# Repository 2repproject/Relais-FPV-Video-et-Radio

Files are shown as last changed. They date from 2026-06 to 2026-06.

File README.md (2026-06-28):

# Projet Relais FPV Video-Radio   

Ici vous trouve manuel d'utilisation et montage de composants puis le model **.stl**, le relais etait fabrique par **CPL Grib du 2REP**

### C'est qua au interieur projet:
* **Manuel de montage Relais fpv.pdf** - Instruction complete comment faire Montage/Parametrage/Composants
* **BOITE RELAIS.stl** - Le boite principal de relais
* **COUVERCLE RELAIS.stl** - Fermeture pour boite
* **vrx adapt 1 antenne.stl** - Adaptation/fixation du VRX au Boite relais (evite que VRX tombe)
* **vrx adapt 2 antenne.stl** - Adaptation/fixation du VRX au Boite relais (evite que VRX tombe)

### Comment telecharger📥:
*  **Telecharger direct au github⚡**:Appuie sur link pour telecharger tout le fichier [https://github.com/ivanopolon/Relais-FPV-Video-et-Radio/archive/refs/heads/main.zip]
*  **Deuxieme link Google Drive** : [https://drive.google.com/drive/folders/1ycLJLeQRHloeQPtYHDW72jciS7_rBkLo?usp=sharing]

### 💡Ce projet est ouvert a toutes les proposition d'amelioration! Si vous avez de idees pour optimiser les modeles, ajouter des fonctionnalites ou adapter les pieces pour autre configuration, votre aide est la bienvenue

**Comment participer🤝:**
  * **Proposer une idee:** Ouvrez un **"Issue"** pour discuter d'une modification ou d'une amelioration (dimensions, design, placement des composants).
  * **Partager vos modifications:** Si vous avez deja modifier un fichier STL de votre cote, n'hesitez pas a soumettre une **"Pull Request"**.
  * **Signaler un probleme:** Si vous remarquez un defaut d'impression ou un problemme d'ajustement sur le pieces, merci de le signaler dans l'onglet **Issues**

### Contacts 📬 
* **Email:** ivan.grib.2003@gmail.com
* **Telegram:** [👉 (https://t.me/Manuel_Gorbatiuc) 👈]
* **Disscusions:** Cree un theme dans onglets **"Disscusions"** pour communique de futurs et votre proposition soit problemme

### Conseils du impression 3D
* **Boite relais et couvercle:**
     *  **Material:** PETG soit PLA
     *  **Remplisage:** 20 a 30% gyroid
     *  **Supports:** Arbreuse (fait tourner model boite relais a 180 en **Y** pour que partie haut du relais etre en bas pendant impression)

 * **Vrx adapteur:**
     *  **Material:** TPU
     *  **Remplisage:** 15% Standart
     *  **Supports:** NON

### Principe de fonctionnement relais Video + Radio

Dans le contexte actuel de l'utilisation des drones (notamment les drones FPV kamikaze), la portée du signal se deminuer à une limite physique majeure : 
* **Zone montagneuses⛰️**
* **Zone forestieres et boisees dense🌳**
* **Environnement urbains**
* **Et tout le obstacle naturel**

Les signaux radio (comme l'ExpressLRS, Crossfire) et les Flux vidéo de differents frequances se coupent dès que le drone passe derrière l'obstacle (perte de la ligne de visée directe ou Line of Sight). 
Quelle que soit la puissance d'émission utilisée (même avec plusieurs Watts), la présence d'une masse physique bloque la reseau, entraînant une perte de contrôle et flux video immédiate.

### 💡 La Solution : Le Relais Embarqué sur Drone Porteur/(Observateur meme temps)
Pour surmonter tout le obstacle, ce projet propose une architecture de retransmission mobile. L'idée est de déployer un module de relais radio et vidéo fixé et allimenter sur un **Drone porteur** (drone mère). 

* **Rôle du drone porteur:** Placé en altitude stratégique, il sert de station relais volante et maintient une liaison parfaite entre l'opérateur au sol et le drone d'action. En meme temps faire observation
* **Fonctionnement Relais:** Le boîtier reçoit en temps réel les commandes de l'opérateur et le flux vidéo du drone d'attaque, puis les retransmet instantanément d'un point à un autre en contournant le relief.
* **Drone kamikaze:** Franchir le mouvement de terain et obstacle puis arrive a son point distribuie son perte signal

Grâce à cette liaison aérienne déportée, le drone peut accomplir sa mission avec succès derrière des obstacles topographiques complexes, garantissant la continuité du signal vidéo et radio jusqu'à l'objectif, peu importent les difficultés du terrain.

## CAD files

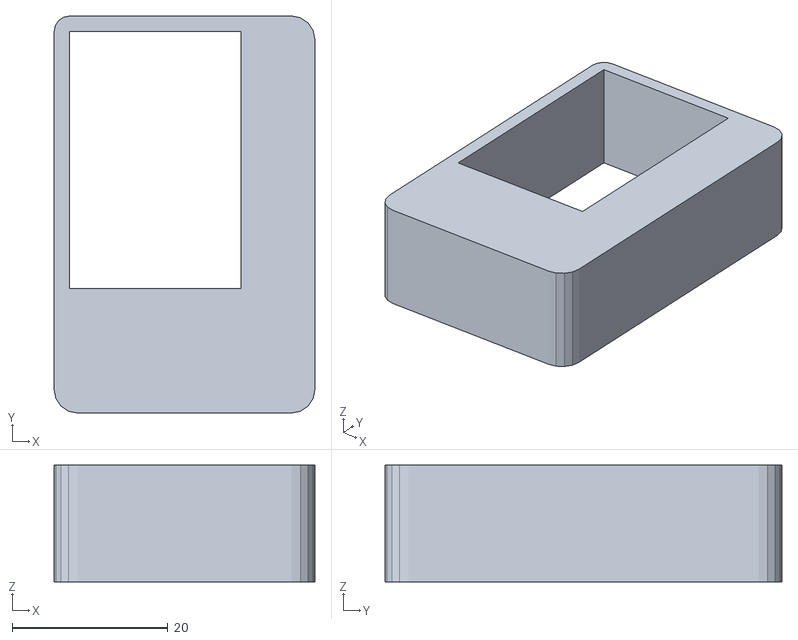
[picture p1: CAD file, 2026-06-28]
vrx adapt correct 1 antenne.stl
33.5 x 51.0 x 15.0

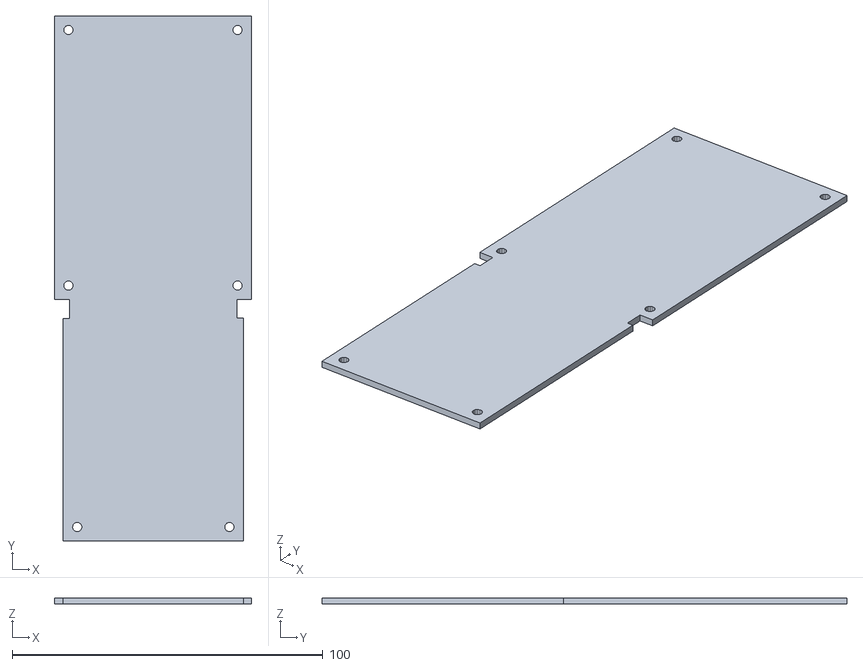
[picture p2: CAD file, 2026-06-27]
COUVERCLE RELAIS.stl
63.4 x 169.0 x 2.00

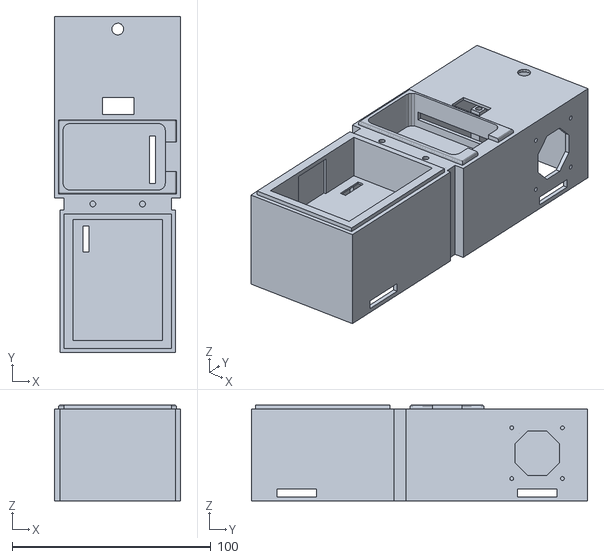
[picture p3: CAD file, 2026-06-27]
BOITE RELAIS.stl
63.4 x 169.0 x 48.2

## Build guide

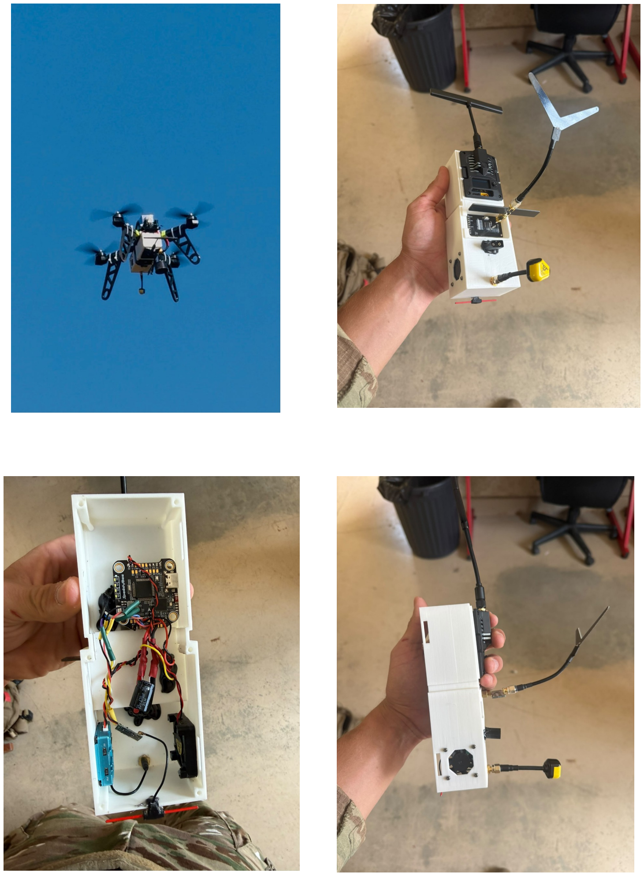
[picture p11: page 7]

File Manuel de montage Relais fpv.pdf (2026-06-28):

## RELAIS FPV Video + Controle

CPL GRIB 2REP

*Video 5.8ghz vers 1.2ghz
*ELRS 2.4ghz vers 915mhz
*Alimenter par drone porteur

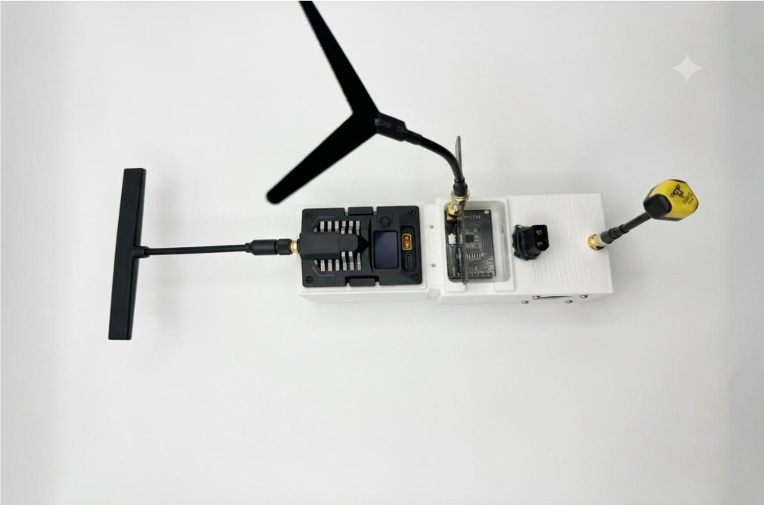
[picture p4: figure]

Dans le cadre de l'intégration drones FPV de type 'kamikaze' sur les guerres modernes, un probleme majeur a été identifié. Lors de la phase d'approche terminale vers l'objectif, la liaison radio directe subit de graves perturbations, allant jusqu'à la perte totale du signal.

Probleme majeur pour drone FPV c’etait:
*Zone montagneuses
*Zone forestieres et boisees dense *Environnement urbains

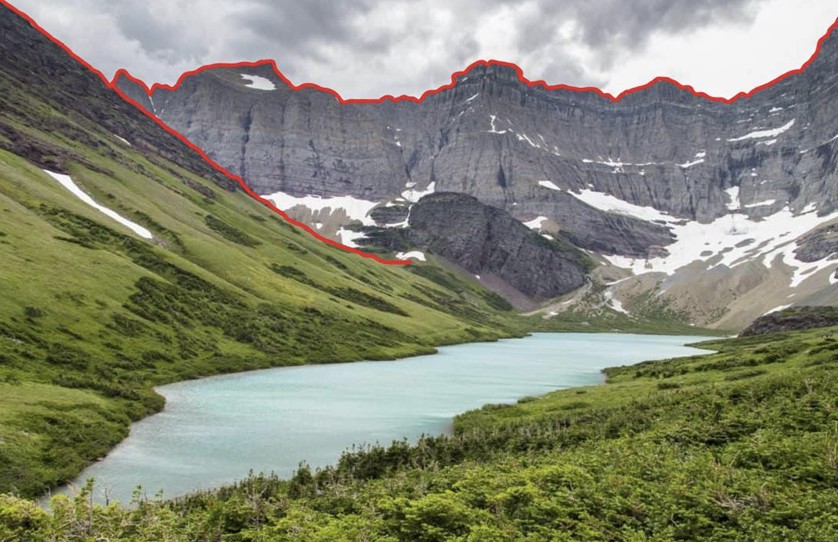
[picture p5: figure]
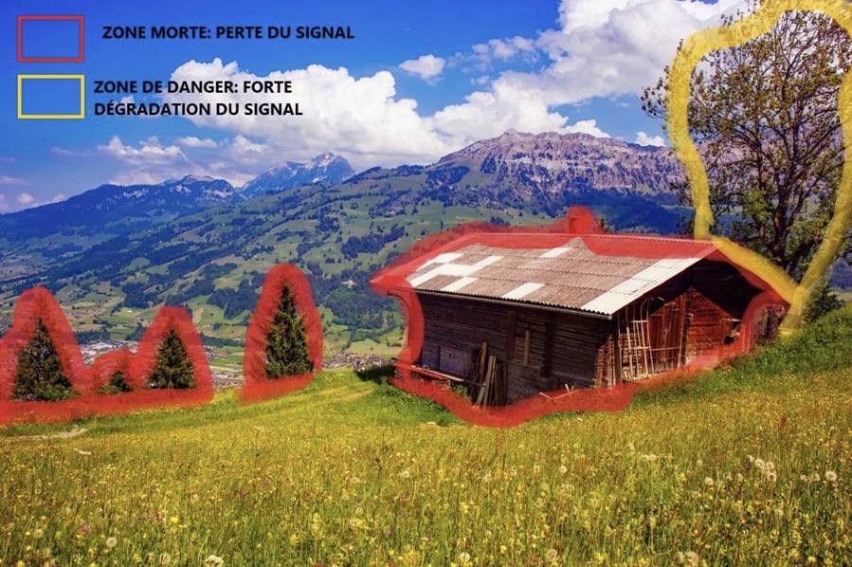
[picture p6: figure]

Les obstacles du terrain pour le flux vidéo et radio | Les limites dues au relief du terrain : les lignes rouges représentent les zones derrières lesquelles la réception vidéo et radio sera perdue.

Pour cette reason ont a trouve une idee s’est de faire un relais qui peut prolonge la distance du drone kamikaze.

Les composants:
*1 VRX 1.2ghz (format fatshark bay )
*1 VTX 5.8ghz
*1 RX ELRS 2.4ghz
*1 TX ELRS 915mhz (reccommander Radiomaster Bandit Micro (avec display)) *1 Ventilo taile 30x30 (trous de visse 20x20)
*1 Cable xt60 avec condensateur
*1 Antenne 1.2 privilige <Patch> soit omni-directionel
*1 Notch filter 868/915 pour VRX 1.2 (evite interferance avec TX 915)Aliexpres *1 Antenne 5.8 taile court omni-directionel
*1 Ralonge de Vtx vers SMA
*1 pack de pin 2.54mm ecart Hauteur pin 11mm (Male et female) Amazon *Boite relais a imprimer (stl a telecharge)
*Pack de vise en gros m3 10 et m2 10
*1 Carte de distribution energie (Entre 6s partage vers 5V et 12V)
soit vous pouvez utilises une Flight Controler rabio pour alimenter composant

En plus…
Drone porteur 7inch a 10inch (privelige analogique 5.8 rx 2.4)
Pied a imprimer pour drone (evite casse le boite relais)
Ralonge XT60 vers Boite ralais a faire vous meme XT60 Male vers XT60 Femele suit 25cm de cable et au fin XT60 Female
Example:

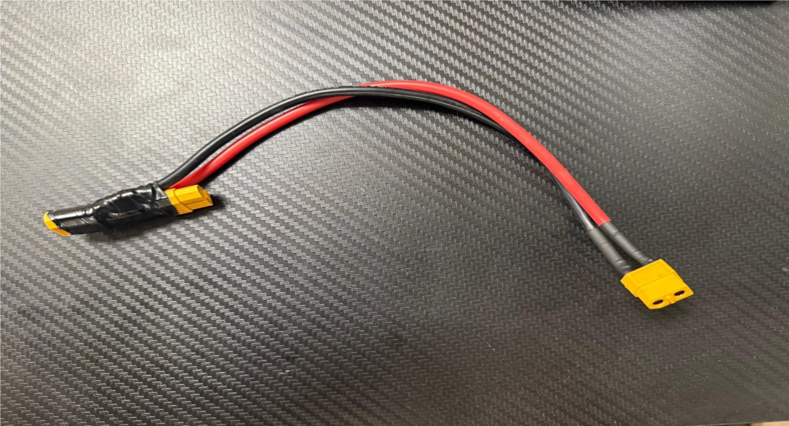
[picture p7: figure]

Le drone kamikaze pour cette relais conseiler utilise avec cette systeme dissus… Video 1.2ghz
RX ELRS 868 soit 915

!Le boite a relais permet vite faire changer le composant qui instale dedant! Pour video possible de utiliser 5.8 vers 5.8 mais risque de gros interferences
Pour controle posible utilise protocol ELRS et Crossfire et aussi posible utilise meme frequances 2.4ghz vers 2.4ghz

### Partie Montage emplacement de chaque piece dans boite interieur

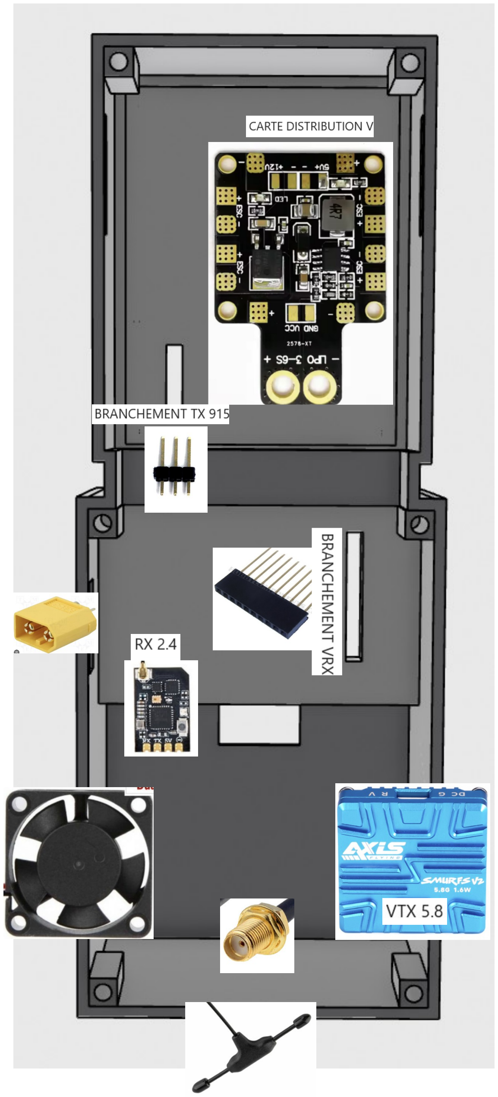
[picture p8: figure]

### Branchement du cable

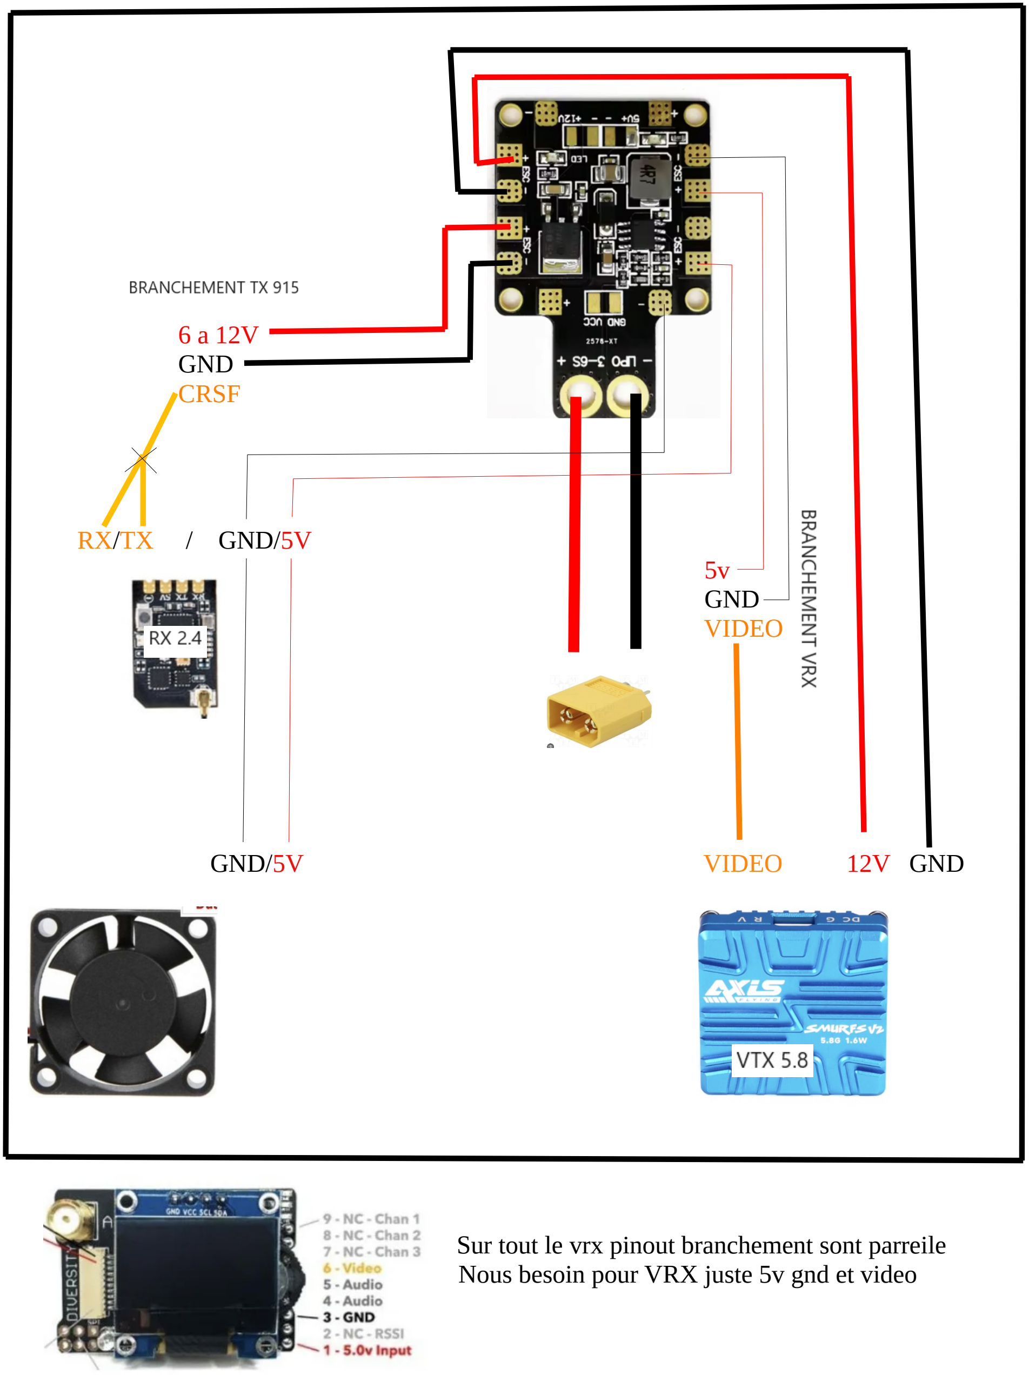
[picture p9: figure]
6 a 12V GND CRSF; RX/TX / GND/5V; 5v GND VIDEO; GND/5V; VIDEO; 12V GND

Sur tout le vrx pinout branchement sont parreile Nous besoin pour VRX juste 5v gnd et video

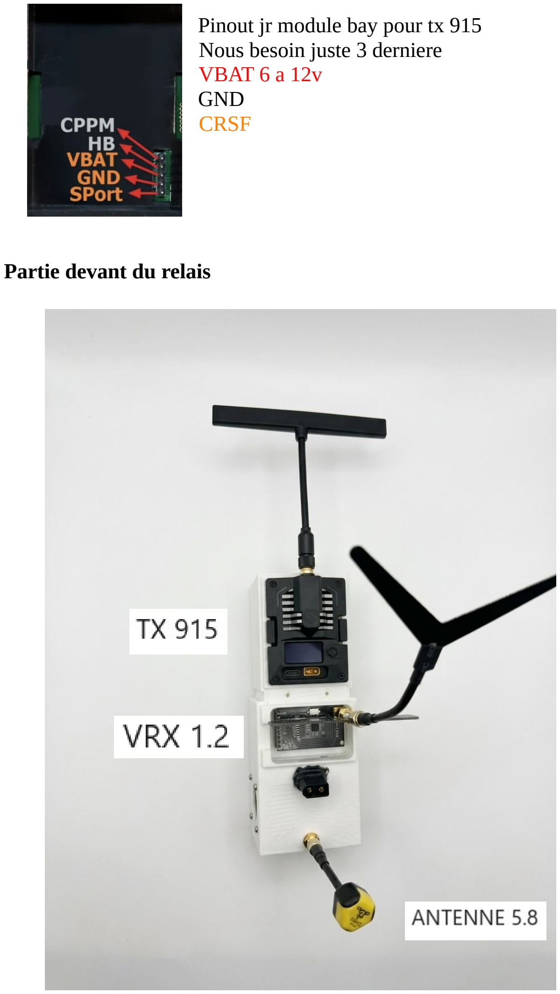
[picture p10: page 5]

### Pinout jr module bay pour tx 915 Nous besoin juste 3 derniere VBAT 6 a 12v GND CRSF

### Partie devant du relais

### Pre-reglage a faire pour connection tx-rx / vrx-vtx

Partie video:
Vtx 5.8 – il faut choisir manuel le canal le plus loin possible (ex RACEBAND 8)
Vrx 1.2 – Choisir n’est porte quelle canaux par rapport de votre antenne (conseille 1280) Suite vous peuvez voir image de votre drone sur canal R8 5.8ghz
reglage de vtx faut faire avant fermeture de boite apres vtx vas transmettre toujour sur cette canal, par rapport de puissance environ 600mw il faut maitre

Partie radio :
TX 915:
Telemetrie - OFF
Pocket rate – 50hz
Dynamic power – ON

RX 2.4:
Telemetrie - 1:4
Pocket rate – 50hz
Dynamic power – ON

Il faut allumer wifi de rx et dans Serial/Uart option verifie si protocol CRSF et Maittre CRSF/Airport baud en place de 420000 changer sur 115200
Si non votre TX et RX pas comprendre la vitesse de langage de deux.

Quand tout le reglage effectuer vous pouvez bindez votre tx avec drone et rx avec manette pour facilite bind conseille utilise binding phrase sur tx915 et drone et aussi rx 2.4 et manett

Allumage:
Pas oublier installe antenne!
Allumer Manette et lunette en premier
En suite Boite relais. de que rx 2.4 bind avec manette ont allume drone

A cette moment votre relais functione!

Si vous instale relais sur drone porteur:
Basculer frequances du drone porteur plus lois de Raceband 8
Le pilote suivre dans bon direction drone Kamikaze

Sur github vous pouvez telecharger tout le fichier STL et lire “README” https://github.com/2repproject/Relais-FPV-Video-et-Radio.git
